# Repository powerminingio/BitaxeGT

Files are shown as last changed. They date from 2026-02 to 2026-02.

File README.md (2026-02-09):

# Bitaxe Gamma Turbo

Bitaxe Gamma Turbo is a dual BM1370 Open Source Bitcoin miner using [esp-miner](https://github.com/bitaxeorg/esp-miner). This project aims to provide a high-performance, energy-efficient Bitcoin mining solution using modern ASIC hardware.

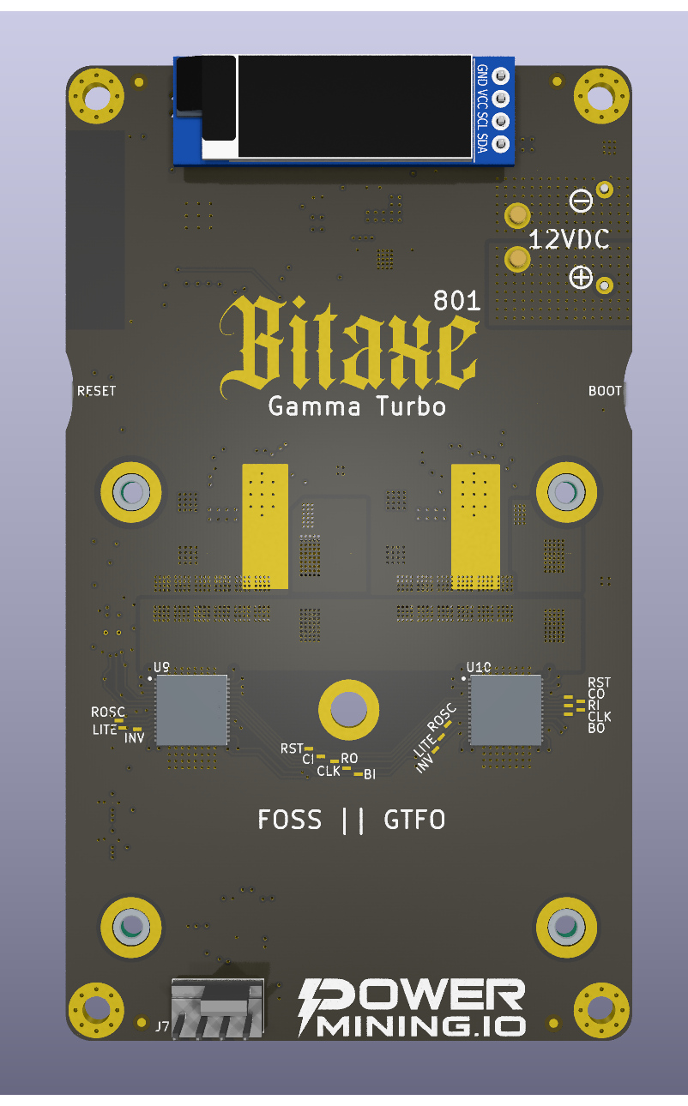
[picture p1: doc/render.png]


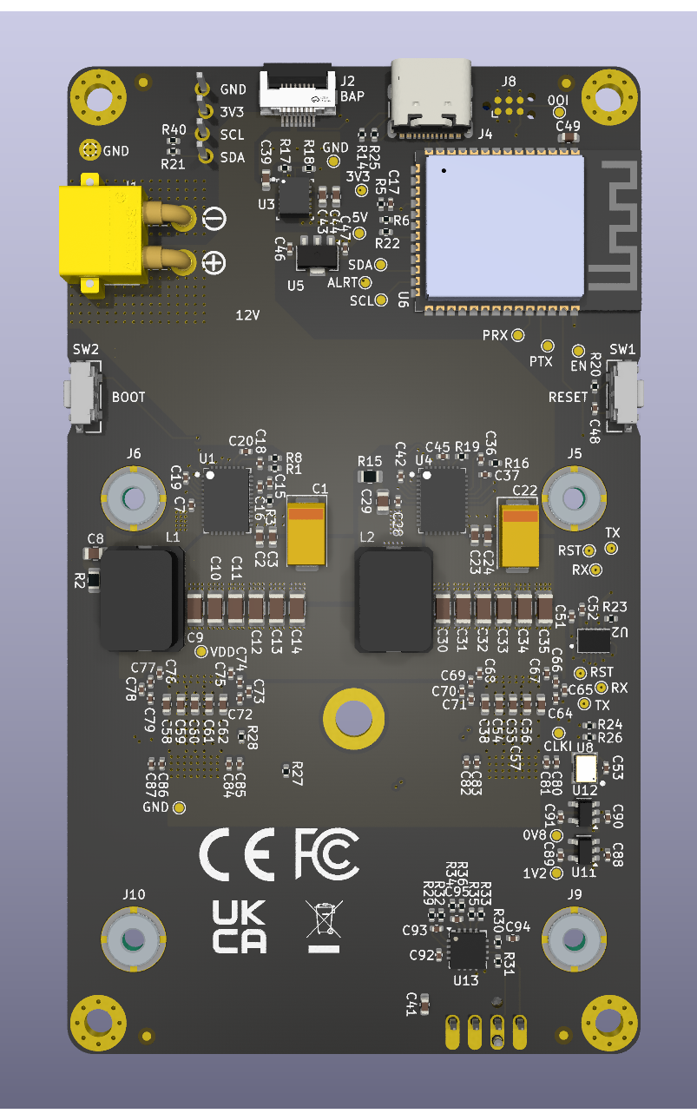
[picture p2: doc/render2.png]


## Version

The first release of the Bitaxe Gamma Turbo (GT) marks the version 801.

Major improvements over the version 800xxx are changes in the selected components and refitting components and headers on the PCB.

## Features

- Dual BM1370 ASIC
- Dual TPS546*
- Improved Mounting Hole selection
- 12V BAP
- EMC2103

The Bitaxe Gamma Turbo is the first iteration of a dual ASIC chip variant and marks the first point of multi-chip devices with modern ASIC hardware.

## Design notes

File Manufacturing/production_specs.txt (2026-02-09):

==== PCB production specifications ====

PCB thickness: 1.6mm
Surface finish: ENIG
Mask color: Black
Silkscreen color: White
Layer thickness: 1oz

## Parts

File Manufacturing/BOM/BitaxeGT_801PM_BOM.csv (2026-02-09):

Qty | Reference | Value | PARTNO | Footprint | DK | Description
1 | C18 | 100pF | CC0402JRNPO9BN101 | Capacitor_SMD:C_0402_1005Metric | 311-1024-1-ND | Unpolarized capacitor, small symbol
1 | C48 | 12pF | CC0402JRNPO9BN120 | Capacitor_SMD:C_0402_1005Metric | 311-1016-1-ND | Unpolarized capacitor, small symbol
2 | C1,C22 | 33uF | T495D336K025ATE300 | Capacitor_Tantalum_SMD:CP_EIA-7343-31_Kemet-D | 399-3882-1-ND | Polarized tantalum capacitor, small US symbol
6 | C15,C19,C36,C42,C46,C47 | 1uF | TMK107B7105KA-T | Capacitor_SMD:C_0402_1005Metric | 587-2984-1-ND | Unpolarized capacitor, small symbol
2 | C16,C37 | 4.7uF | GRM155R61A475MEAAD | Capacitor_SMD:C_0402_1005Metric | 490-14306-1-ND | Unpolarized capacitor, small symbol
19 | C2,C3,C23,C24,C38,C39,C41,C43,C44,C49,C54,C55,C56,C57,C58,C59,C60,C61,C62 | 10uF | GRM188R61E106KA73D | Capacitor_SMD:C_0603_1608Metric | 490-18214-1-ND | Unpolarized capacitor, small symbol
2 | C20,C45 | 33pF | KGM05ACG1E330JH | Capacitor_SMD:C_0402_1005Metric | 478-KGM05ACG1E330JHCT-ND | Unpolarized capacitor, small symbol
28 | C64,C65,C66,C67,C68,C69,C70,C71,C72,C73,C74,C75,C76,C77,C78,C79,C80,C81,C82,C83,C84,C85,C86,C87,C88,C89,C90,C91 | 1uF | EMK105BJ105MV-F | Capacitor_SMD:C_0402_1005Metric | 587-5514-1-ND | Unpolarized capacitor, small symbol
8 | C7,C17,C28,C51,C52,C53,C92,C94 | 0.1uF | KGM05AR71C104KH | Capacitor_SMD:C_0402_1005Metric | 478-KGM05AR71C104KHCT-ND | Unpolarized capacitor, small symbol
2 | C8,C29 | 1000pF | CC0805KRX7R9BB102 | Capacitor_SMD:C_0805_2012Metric | 311-1127-1-ND | Unpolarized capacitor, small symbol
12 | C9,C10,C11,C12,C13,C14,C30,C31,C32,C33,C34,C35 | 100uF | CL31A107MQHNNNE | Capacitor_SMD:C_1206_3216Metric | 1276-1782-1-ND | Unpolarized capacitor, small symbol
2 | C93,C95 | 470pF | GRM1555C1H471JA01D | Capacitor_SMD:C_0402_1005Metric | 490-1297-1-ND | Unpolarized capacitor, small symbol
1 | J1 | XT30 | XT30PW-M | bitaxe:XT30PW-M | ~
1 | J2 | Conn_01x08 | FFC2B35-08-T | bitaxe:FPC-SMD_P0.50-8P_FGS-XJ-H2.0 | 2073-FFC2B35-08-TCT-ND
1 | J4 | USB_C_Receptacle_USB2.0 | USB4105-GF-A | bitaxe:USB_C_Receptacle_GCT_USB4105-xx-A | 2073-USB4105-GF-ACT-ND | USB 2.0-only Type-C Receptacle connector
1 | J7 | Conn_01x04 | 0470531000 | bitaxe:470531000 | WM4330-ND | Generic connector, single row, 01x04, script generated (kicad-library-utils/schlib/autogen/connector/)
4 | J5,J6,J9,J10 | Screw_Terminal_01x01 | 9774005360R | bitaxe:WA-SMSI_9774005360 |  | WA-SMSI SMT STEEL SPACER M3 thread
2 | L1,L2 | 300nH | SLC1175-271MEC | bitaxe:SLC1175-271MEC_COC |  | Inductor
1 | R27 | 2k | RT0402BRD072KL | Resistor_SMD:R_0402_1005Metric | YAG2303CT-ND | Resistor, small US symbol
1 | R31 | 5.6k | RC0402FR-075K6L | Resistor_SMD:R_0402_1005Metric | 311-5.6KLRCT-ND | Resistor, small US symbol
2 | R1,R8 | 49.9 | RC0402FR-0749R9L | Resistor_SMD:R_0402_1005Metric | 311-49.9LRCT-ND | Resistor, small US symbol
2 | R14,R25 | 5.1k | RMCF0402JT5K10 | Resistor_SMD:R_0402_1005Metric | RMCF0402JT5K10CT-ND
2 | R17,R23 | 20k | RC0402FR-0720KL | Resistor_SMD:R_0402_1005Metric | 311-20.0KLRCT-ND | Resistor, small US symbol
2 | R2,R15 | 1 | ESR10EZPJ1R0 | Resistor_SMD:R_0805_2012Metric | RHM1KTR-ND | Resistor, small US symbol
3 | R21,R22,R40 | 4.7k | RC0402JR-074K7L | Resistor_SMD:R_0402_1005Metric | 311-4.7KJRCT-ND | Resistor, small US symbol
2 | R26,R28 | 1k | RC0402FR-071KL | Resistor_SMD:R_0402_1005Metric | 311-1.00KLRCT-ND | Resistor, small US symbol
4 | R29,R32,R34,R36 | 0 | RC0402JR-070RL | Resistor_SMD:R_0402_1005Metric | 311-0.0JRCT-ND | Resistor, small US symbol
2 | R3,R16 | 10 | RC0402FR-0710RL | Resistor_SMD:R_0402_1005Metric | 311-10.0LRCT-ND | Resistor, small US symbol
8 | R5,R6,R18,R19,R20,R24,R30,R33 | 10k | RC0402JR-0710KL | Resistor_SMD:R_0402_1005Metric | 311-10KJRCT-ND | Resistor, small US symbol
2 | SW1,SW2 | SWITCH-SPST | TL3330AF130QG | bitaxe:SW_TL3330AF130QG_EWI | EG4388CT-ND
1 | U2 | SN74AVC4T774 | SN74AXC4T774BQBR | bitaxe:BQB0016A-MFG | 296-SN74AXC4T774BQBRCT-ND
1 | U3 | TPSM861253RDXR | TPSM861253RDXR | bitaxe:TPSM863257RDX | 296-TPSM861253RDXRCT-ND | 17V input, stepdown, 3.3V 1A output, DC/DC converter, 7-PowerFQFN Module
1 | U5 | L78L05_SOT89 | UA78L05ACPK | Package_TO_SOT_SMD:SOT-89-3 | 296-11118-1-ND | Positive 100mA 30V Linear Regulator, Fixed Output 5V, SOT-89
1 | U6 | ESP32-S3-WROOM-1 | ESP32-S3-WROOM-1-N16R8 | bitaxe:ESP32-S3-WROOM-1 | 1965-ESP32-S3-WROOM-1-N16R8CT-ND | 2.4 GHz WiFi (802.11 b/g/n) and Bluetooth ® 5 (LE) module Built around ESP32S3 series of SoCs, Xtensa ® dualcore 32bit LX7 microprocessor Flash up to 16 MB, PSRAM up to 8 MB 36 GPIOs, rich set of peripherals Onboard PCB antenna
1 | U8 | 25MHz | SX3M25.000E20F30THN | bitaxe:SMD3225-4P | 5852-SX3M25.000E20F30THNTR-ND
1 | U11 | MCP1824T-1202E/OT | MCP1824T-1202E/OT | Package_TO_SOT_SMD:SOT-23-5 | MCP1824T-1202E/OTCT-ND
1 | U12 | MCP1824T-0802E | MCP1824T-0802E/OT | Package_TO_SOT_SMD:SOT-23-5 | MCP1824T-0802E/OTCT-ND
1 | U13 | EMC2103-2 | EMC2103-4-AP-TR | Package_DFN_QFN:QFN-16-1EP_4x4mm_P0.65mm_EP2.1x2.1mm | 150-EMC2103-4-AP-CT-ND
2 | U1,U4 | TPS546D24S | TPS546D24SRVFR | bitaxe:LQFN40-CLIP | 296-TPS546D24SRVFRCT-ND
2 | U9,U10 | BM1370_mode1 |  | bitaxe:BM1370

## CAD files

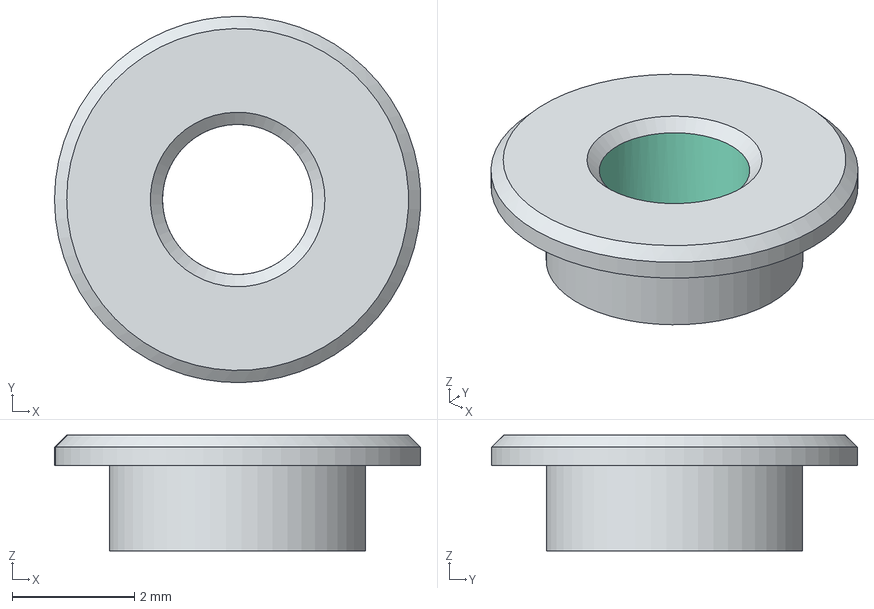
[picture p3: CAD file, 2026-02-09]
3d/STP_9774005360.stp
6.00 x 6.00 x 1.90 mm

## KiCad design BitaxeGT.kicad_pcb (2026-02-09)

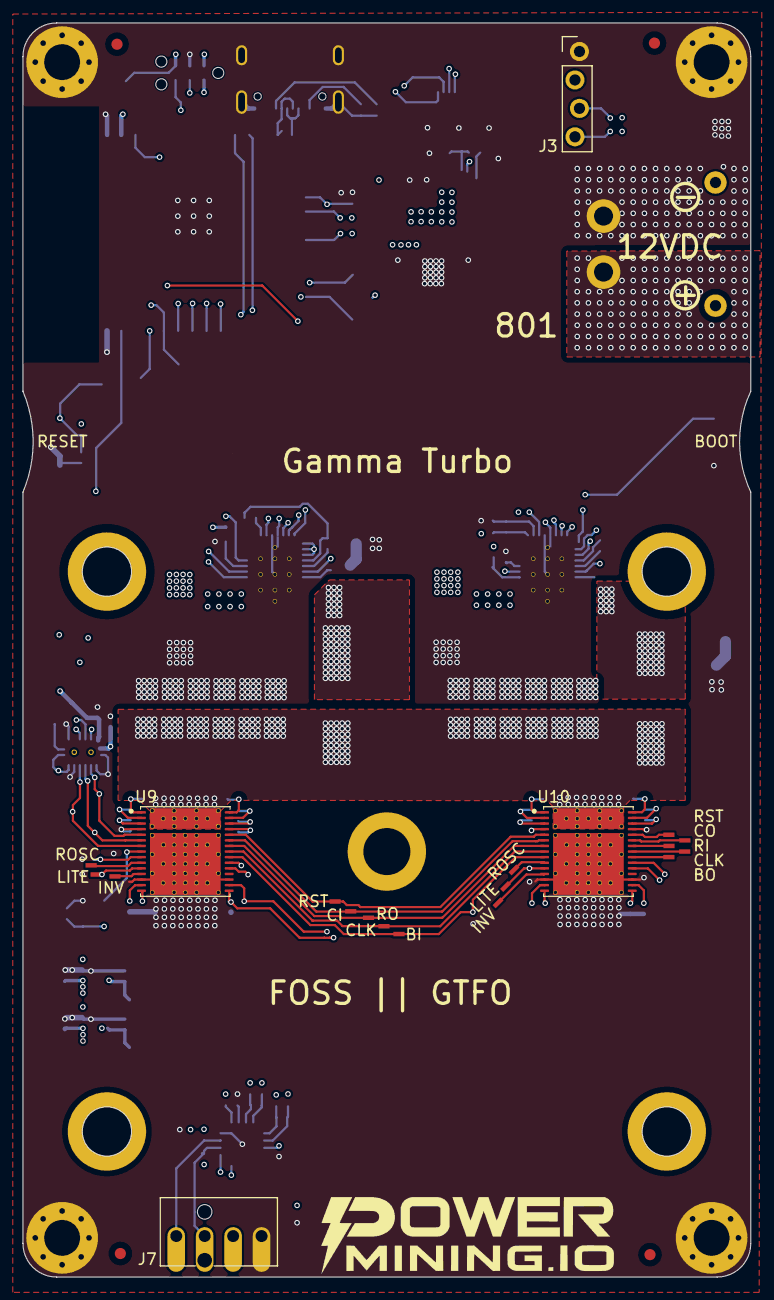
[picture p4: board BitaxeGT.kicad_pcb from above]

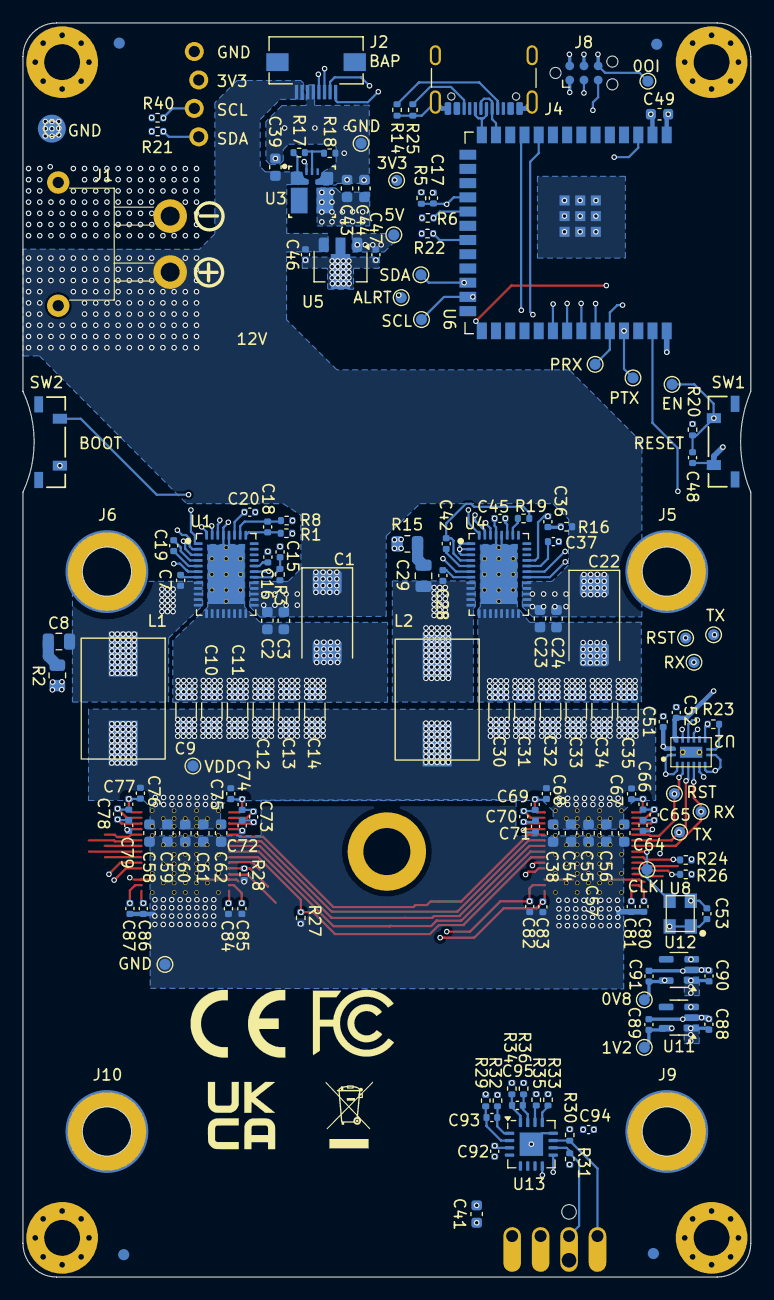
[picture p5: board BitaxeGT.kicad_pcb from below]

Board: 6 copper layers, 65.0 x 112.0 mm, 191 parts (163 on the bottom side), 98 nets.

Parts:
C1, C22: 33uF; CP_EIA-7343-31_Kemet-D
C2, C3, C23, C24, C38, C39, C41, C43, C44, C49, C54, C55, C56, C57, C58, C59, C60, C61, C62: 10uF; C_0603_1608Metric
C7, C17, C28, C51, C52, C53, C92, C94: 0.1uF; C_0402_1005Metric
C8, C29: 1000pF; C_0805_2012Metric
C9, C10, C11, C12, C13, C14, C30, C31, C32, C33, C34, C35: 100uF; C_1206_3216Metric
C15, C19, C36, C42, C46, C47, C64, C65, C66, C67, C68, C69, C70, C71, C72, C73, C74, C75, C76, C77, C78, C79, C80, C81, C82, C83, C84, C85, C86, C87, C88, C89, C90, C91: 1uF; C_0402_1005Metric
C16, C37: 4.7uF; C_0402_1005Metric
C18: 100pF; C_0402_1005Metric
C20, C45: 33pF; C_0402_1005Metric
C48: 12pF; C_0402_1005Metric
C93, C95: 470pF; C_0402_1005Metric
FID1, FID2, FID3, FID4: Fiducial; Fiducial_1mm_Mask2mm
H1, H2, H3, H4: MountingHole_Pad; MountingHole_3.2mm_M3_Pad_Via
HS1: Heatsink; Heatsink-5hole-BitaxeGT
J1: XT30; XT30PW-M
J2: Conn_01x08; FPC-SMD_P0.50-8P_FGS-XJ-H2.0
J3: Conn_01x04; PinHeader_1x04_P2.54mm_Vertical_shifted
J4: USB_C_Receptacle_USB2.0; USB_C_Receptacle_GCT_USB4105-xx-A
J5, J6, J9, J10: Screw_Terminal_01x01; WA-SMSI_9774005360
J7: Conn_01x04; 470531000
J8: TC2030-IDC; Tag-Connect_TC2030-IDC-NL_2x03_P1.27mm_Vertical
L1, L2: 300nH; SLC1175-271MEC_COC
Logo: 25mm; PM_logo_25mm
NT1, NT2: NetTie_2; NetTie-2_SMD_Pad0.2mmx1mm
R1, R8: 49.9; R_0402_1005Metric
R2, R15: 1; R_0805_2012Metric
R3, R16: 10; R_0402_1005Metric
R5, R6, R18, R19, R20, R24, R30, R33: 10k; R_0402_1005Metric
R14, R25: 5.1k; R_0402_1005Metric
R17, R23: 20k; R_0402_1005Metric
R21, R22, R40: 4.7k; R_0402_1005Metric
R26, R28: 1k; R_0402_1005Metric
R27: 2k; R_0402_1005Metric
R29, R32, R34, R36: 0; R_0402_1005Metric
R31: 5.6k; R_0402_1005Metric
R35: Rtrip; R_0402_1005Metric
SW1, SW2: SWITCH-SPST; SW_TL3330AF130QG_EWI
TP1, TP9: RST; TestPoint_Pad_1.0x0.4mm
TP2: CI; TestPoint_Pad_1.0x0.4mm
TP3: RO; TestPoint_Pad_1.0x0.4mm
TP4: CLKI; TestPoint_Pad_D1.0mm
TP5: BO; TestPoint_Pad_1.0x0.4mm
TP6, TP11: CLK; TestPoint_Pad_1.0x0.4mm
TP7: RI; TestPoint_Pad_1.0x0.4mm
TP8: CO; TestPoint_Pad_1.0x0.4mm
TP10, TP16: ROSC; TestPoint_Pad_1.0x0.4mm
TP12, TP20: LITE; TestPoint_Pad_1.0x0.4mm
TP13: BI; TestPoint_Pad_1.0x0.4mm
TP14, TP21: INV; TestPoint_Pad_1.0x0.4mm
TP15: VDD; TestPoint_Pad_D1.0mm
TP17, TP25, TP28: GND; TestPoint_Pad_D1.0mm
TP18: 1V2; TestPoint_Pad_D1.0mm
TP19: 0V8; TestPoint_Pad_D1.0mm
TP22: ALRT; TestPoint_Pad_D1.0mm
TP23: SDA; TestPoint_Pad_D1.0mm
TP24: SCL; TestPoint_Pad_D1.0mm
TP26, TP35: RST; TestPoint_Pad_D1.0mm
TP27: 5V; TestPoint_Pad_D1.0mm
TP29: EN; TestPoint_Pad_D1.0mm
TP30, TP37: TX; TestPoint_Pad_D1.0mm
TP31, TP38: RX; TestPoint_Pad_D1.0mm
TP32: PTX; TestPoint_Pad_D1.0mm
TP33: PRX; TestPoint_Pad_D1.0mm
TP34: 3V3; TestPoint_Pad_D1.0mm
TP36: IO0; TestPoint_Pad_D1.0mm
U1, U4: TPS546D24S; LQFN40-CLIP
U2: SN74AVC4T774; BQB0016A-MFG
U3: TPSM861253RDXR; TPSM863257RDX
U5: L78L05_SOT89; SOT-89-3
U6: ESP32-S3-WROOM-1
U8: 25MHz; SMD3225-4P
U9, U10: BM1370_mode1; BM1370_JB
U11: MCP1824T-1202E/OT; SOT-23-5
U12: MCP1824T-0802E; SOT-23-5
U13: EMC2103-2; QFN-16-1EP_4x4mm_P0.65mm_EP2.1x2.1mm

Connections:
/3V3: C43.1, C44.1, C49.1, C52.1, C92.1, J3.2, J8.2, R6.2, R20.2, R21.1, R22.1, R31.2, R33.2, R40.1, TP34.1, U2.15 (VCCB), U3.3 (VOUT), U3.7 (VOS), U6.2 (3V3), U13.3 (VDD)
/5V: C47.2, C88.2, C90.2, C94.1, R30.2, TP27.1, U5.1 (OUT), U11.1 (VIN), U11.3 (EN), U12.1 (VIN), U12.3 (EN)
/12V: C1.1, C2.1, C3.1, C22.1, C23.1, C24.1, C39.1, C41.1, C46.2, J1.1 (+V), J2.1, J2.2, J7.2, R3.1, R16.1, R17.2, U1.21 (PVIN), U1.22 (PVIN), U1.23 (PVIN), U1.24 (PVIN), U1.25 (PVIN), U3.1 (VIN), U4.21 (PVIN), U4.22 (PVIN), U4.23 (PVIN), U4.24 (PVIN), U4.25 (PVIN), U5.3 (IN)
/ASIC/0V8: C82.2, C85.2, C91.2, TP19.1, U9.17 (VDDIO_08_1), U10.14 (VDDIO_08_0), U12.5 (VOUT)
/ASIC/0V8_1: C80.2, U9.14 (VDDIO_08_0)
/ASIC/0V8_2: C87.2, U10.17 (VDDIO_08_1)
/ASIC/1V2: C51.1, C53.1, C83.2, C84.2, C89.2, TP18.1, U2.7 (DIR3), U2.8 (DIR4), U2.16 (VCCA), U8.1 (EN), U8.4 (VIN), U9.16 (VDDIO_12_1), U10.15 (VDDIO_12_0), U11.5 (VOUT)
/ASIC/1V2_1: C81.2, U9.15 (VDDIO_12_0)
/ASIC/1V2_2: C86.2, U10.16 (VDDIO_12_1)
/ASIC/BI: R24.2, U9.9 (BI)
/ASIC/CLKI: TP4.1, U8.3 (OUT), U9.8 (CLKI)
/ASIC/RST_1V2: TP35.1, U2.3 (A1), U9.5 (NRSTI)
/ASIC/RST_3V3: TP26.1, U2.14 (B1), U6.39 (GPIO1/TOUCH1/ADC1_CH0)
/ASIC/RX_1V2: TP38.1, U2.5 (A3), U9.7 (RO)
/ASIC/RX_3V3: TP31.1, U2.12 (B3), U6.11 (GPIO18/U1RXD/ADC2_CH7/CLK_OUT3)
/ASIC/TEMP1_N: R36.2, U9.21 (TEMP_N)
/ASIC/TEMP1_P: R34.2, U9.20 (TEMP_P)
/ASIC/TEMP2_N: R32.2, U10.21 (TEMP_N)
/ASIC/TEMP2_P: R29.2, U10.20 (TEMP_P)
/ASIC/TX_1V2: TP37.1, U2.4 (A2), U9.6 (CI)
/ASIC/TX_3V3: TP30.1, U2.13 (B2), U6.10 (GPIO17/U1TXD/ADC2_CH6)
/ESP32/EN: C48.1, J8.1, R20.1, SW1.2, TP29.1, U6.3 (EN)
/ESP32/IO0: J8.6, SW2.1, TP36.1, U6.27 (GPIO0/BOOT*)
/ESP32/PWR_EN: C17.1, R5.2, U1.27 (EN/UVLO), U4.27 (EN/UVLO), U6.18 (GPIO10/TOUCH10/ADC1_CH9/FSPICS0/FSPIIO4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)
/ESP32/P_RX: J8.5, TP33.1, U6.36 (U0RXD/GPIO44/CLK_OUT2)
/ESP32/P_TX: J8.3, TP32.1, U6.37 (U0TXD/GPIO43/CLK_OUT1)
/ESP32/SCL: J3.3, R40.2, TP24.1, U1.3 (PMB_CLK), U6.25 (GPIO48/SPICLK_N/SUBSPICLK_N_DIFF), U13.9 (SMCLK)
/ESP32/SDA: J3.4, R21.2, TP23.1, U1.2 (PMB_DATA), U6.24 (GPIO47/SPICLK_P/SUBSPICLK_P_DIFF), U13.8 (SMDATA)
/ESP32/SMB_ALRT: R22.2, TP22.1, U1.6 (SMB_ALRT), U6.21 (GPIO13/TOUCH13/ADC2_CH2/FSPIQ/FSPIIO7/S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)
/ESP32/USB_D+: J4.A6 (D+), J4.B6 (D+), U6.14 (GPIO20/U1CTS/ADC2_CH9/CLK_OUT1/USB_D+)
/ESP32/USB_D-: J4.A7 (D-), J4.B7 (D-), U6.13 (GPIO19/U1RTS/ADC2_CH8/CLK_OUT2/USB_D-)
/Power/AGND1: C15.1, C20.1, NT1.2, U1.37 (AGND)
/Power/AGND2: C36.1, C45.1, NT2.2, U4.1 (PGD), U4.2 (PMB_DATA), U4.3 (PMB_CLK), U4.6 (SMB_ALRT), U4.29 (MSEL2), U4.37 (AGND)
/Power/BCX_CLK: U1.39 (BCX_CLK), U4.39 (BCX_CLK)
/Power/BCX_DAT: U1.40 (BCX_DAT), U4.40 (BCX_DAT)
/Power/BP1v5_1: C19.1, U1.4 (BP1V5)
/Power/BP1v5_2: C42.1, R19.1, U4.4 (BP1V5)
/Power/PGOOD: R6.1, U1.1 (PGD), U6.19 (GPIO11/TOUCH11/ADC2_CH0/FSPID/FSPIIO5/S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)
/Power/SW1: C7.2, C8.1, L1.1, U1.8 (SW), U1.9 (SW), U1.10 (SW), U1.11 (SW), U1.12 (SW)
/Power/SW2: C28.2, C29.1, L2.1, U4.8 (SW), U4.9 (SW), U4.10 (SW), U4.11 (SW), U4.12 (SW)
/Power/SYNC: U1.38 (SYNC), U4.38 (SYNC)
/Power/V5reg_1: C16.2, U1.28 (VDD5)
/Power/V5reg_2: C37.2, U4.28 (VDD5)
/Power/VSHARE: C20.2, C45.2, U1.35 (VSHARE), U4.35 (VSHARE)
/VDD: C9.2, C10.2, C11.2, C12.2, C13.2, C14.2, C30.2, C31.2, C32.2, C33.2, C34.2, C35.2, C38.1, C54.1, C55.1, C56.1, C57.1, C58.1, C59.1, C60.1, C61.1, C62.1, C67.2, C68.1, C75.2, C76.1, L1.2, L2.2, R1.2, TP15.1, U9.31 (VDD), U10.31 (VDD)
/fan/FAN_PWM: J7.4, R30.1, U13.11 (FAN)
/fan/FAN_TACH: J7.3, R31.1, U13.10 (TACH)
GND: C1.2, C2.2, C3.2, C9.1, C10.1, C11.1, C12.1, C13.1, C14.1, C16.1, C17.2, C22.2, C23.2, C24.2, C30.1, C31.1, C32.1, C33.1, C34.1, C35.1, C37.1, C38.2, C39.2, C41.2, C43.2, C44.2, C46.1, C47.1, C48.2, C49.2, C51.2, C52.2, C53.2, C54.2, C55.2, C56.2, C57.2, C58.2, C59.2, C60.2, C61.2, C62.2, C64.1, C71.2, C72.1, C79.2, C80.1, C81.1, C82.1, C83.1, C84.1, C85.1, C86.1, C87.1, C88.1, C89.1, C90.1, C91.1, C92.2, C94.2, H1.1, H2.1, H3.1, H4.1, J1.2 (GND), J2.3, J2.4, J3.1, J4.A1 (GND), J4.B1 (GND), J4.S1 (SHIELD), J7.1, J8.4, NT1.1, NT2.1, R2.2, R5.1, R8.1, R14.1, R15.2, R18.1, R23.1, R24.1, R25.1, R26.1, R27.1, R28.1, R35.1, SW1.1, SW2.2, TP17.1, TP25.1, TP28.1, U1.13 (PGND), U1.14 (PGND), U1.15 (PGND), U1.16 (PGND), U1.17 (PGND), U1.18 (PGND), U1.19 (PGND), U1.20 (PGND), U1.36 (NC), U1.41 (PAD), U2.1 (DIR1), U2.2 (DIR2), U2.6 (A4), U2.10 (GND), U3.4 (PGND), U4.13 (PGND), U4.14 (PGND), U4.15 (PGND), U4.16 (PGND), U4.17 (PGND), U4.18 (PGND), U4.19 (PGND), U4.20 (PGND), U4.36 (NC), U4.41 (PAD), U5.2 (GND), U6.1 (GND), U6.40 (GND), U6.41 (GND), U8.2 (GND), U9.4 (VSS), U9.13 (PLL_VSS), U9.18 (VSS), U9.27 (VSS), U9.32 (VSS), U10.4 (VSS), U10.13 (PLL_VSS), U10.18 (VSS), U10.27 (VSS), U10.32 (VSS), U11.2 (GND), U12.2 (GND), U13.12 (GND), U13.17 (PAD)
unnamed: C8.2, R2.1
unnamed: C29.2, R15.1
unnamed: J2.5, U6.32 (MTCK/GPIO39/CLK_OUT3/SUBSPICS1)
unnamed: J2.6, U6.33 (MTDO/GPIO40/CLK_OUT2)
unnamed: J2.7, U6.34 (MTDI/GPIO41/CLK_OUT1)
unnamed: J2.8, U6.35 (MTMS/GPIO42)
unnamed: J4.A5 (CC1), R14.2
unnamed: J4.B5 (CC2), R25.2
unnamed: C15.2, R3.2, U1.26 (AVIN)
unnamed: C7.1, U1.7 (BOOT)
unnamed: C19.2, U1.5 (DRTN)
unnamed: C18.2, R8.2, U1.34 (GOSNS)
unnamed: C18.1, R1.1, U1.33 (VOSNS)
unnamed: R23.2, U2.9 (OE)
unnamed: R17.1, R18.2, U3.6 (EN)
unnamed: C36.2, R16.2, U4.26 (AVIN)
unnamed: C28.1, U4.7 (BOOT)
unnamed: C42.2, U4.5 (DRTN)
unnamed: R19.2, U4.34 (GOSNS)
unnamed: TP14.1, U9.12 (INV_CLKO)
unnamed: R26.2, TP12.1, U9.11 (LITE_PAD)
unnamed: TP10.1, U9.10 (ROSC_SEL)
unnamed: C64.2, C65.1, U9.3 (VDD1_0)
unnamed: C65.2, C66.1, U9.2 (VDD2_0)
unnamed: C66.2, C67.1, U9.1 (VDD3_0)
unnamed: R27.2, TP13.1, U9.22 (BO), U10.9 (BI)
unnamed: TP5.1, U10.22 (BO)
unnamed: TP2.1, U9.25 (CO), U10.6 (CI)
unnamed: TP11.1, U9.23 (CLKO), U10.8 (CLKI)
unnamed: TP6.1, U10.23 (CLKO)
unnamed: TP8.1, U10.25 (CO)
unnamed: TP21.1, U10.12 (INV_CLKO)
unnamed: R28.2, TP20.1, U10.11 (LITE_PAD)
unnamed: TP1.1, U9.26 (NRSTO), U10.5 (NRSTI)
unnamed: TP9.1, U10.26 (NRSTO)
unnamed: TP7.1, U10.24 (RI)
unnamed: TP3.1, U9.24 (RI), U10.7 (RO)
unnamed: TP16.1, U10.10 (ROSC_SEL)
unnamed: C70.2, C71.1, C72.2, C73.1, U9.28 (VDD1_1), U10.3 (VDD1_0)
unnamed: C78.2, C79.1, U10.28 (VDD1_1)
unnamed: C69.2, C70.1, C73.2, C74.1, U9.29 (VDD2_1), U10.2 (VDD2_0)
unnamed: C77.2, C78.1, U10.29 (VDD2_1)
unnamed: C68.2, C69.1, C74.2, C75.1, U9.30 (VDD3_1), U10.1 (VDD3_0)
unnamed: C76.2, C77.1, U10.30 (VDD3_1)
unnamed: C93.2, R32.1, U13.1 (DN1)
unnamed: C95.2, R36.1, U13.15 (DN2)
unnamed: C93.1, R29.1, U13.2 (DP1)
unnamed: C95.1, R34.1, U13.16 (DP2)
unnamed: R33.1, U13.13 (SHDN_SEL)
unnamed: R35.2, U13.14 (TRIP_SET)

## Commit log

2026-02-09 Various changes in PCB
    - Updated BM1370 footprint
    - Added treaded spacers for heatsink
    - Added component references on silkscreen
    - Added PM logo
    - Added BITAXE logo in solder mask expansion level
    - Exported BOM and Gerber files
    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
    [BitaxeGT-B_Cu.gbr, BitaxeGT-B_Mask.gbr, BitaxeGT-B_Paste.gbr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]
2026-02-09 ASIC.sch update in BM footprint
    [ASIC.kicad_sch]
